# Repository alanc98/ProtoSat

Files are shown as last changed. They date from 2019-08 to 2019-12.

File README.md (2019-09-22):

# ProtoSat
Proto-Sat Software, Designs,  and Documentation

# What is it?
Proto-Sat is a compact prototyping platform for a number of purposes including:
* Flight Software Prototyping and testing
* Robotics
* Any general Portable Raspberry Pi Projects

The Proto-Sat Zero consists of:
* A custom PCB
* A Raspberry Pi Zero W
* An Adafruit PowerBoost 1000C Battery/Charge controller breakout
* A BerryIMU 10 DOF IMU with a number of sensors
* An Adafruit APDS9660 Light/Proximity Sensor
* An Adafruit 1.3" OLED display for a simple UI

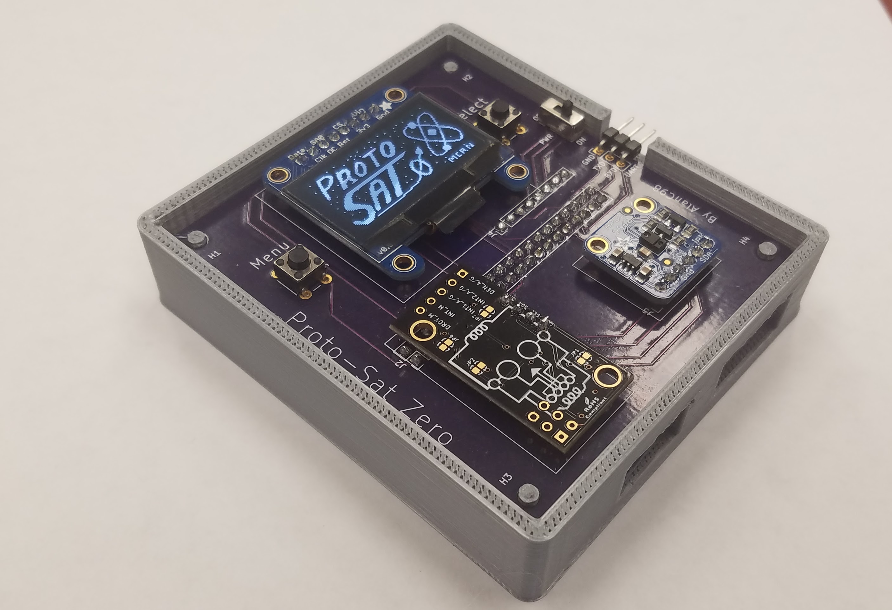
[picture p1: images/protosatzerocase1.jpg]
ProtoSatZero with 3d printed case


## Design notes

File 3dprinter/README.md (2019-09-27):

# ProtoSat 3d Printer designs
Proto-Sat 3d Printer STL files.

## ProtoSat 3d printed case:
ProtoSatZero with 3d printed case

## ProtoSat 3d printed badge holder:
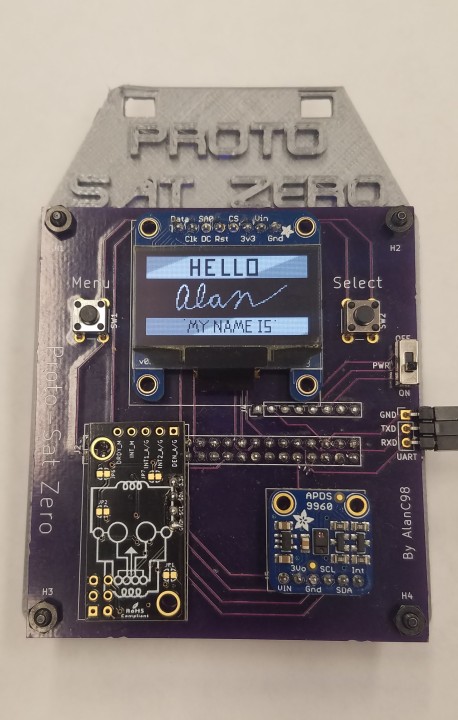
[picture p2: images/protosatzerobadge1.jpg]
ProtoSatZero with 3d printed badge holder


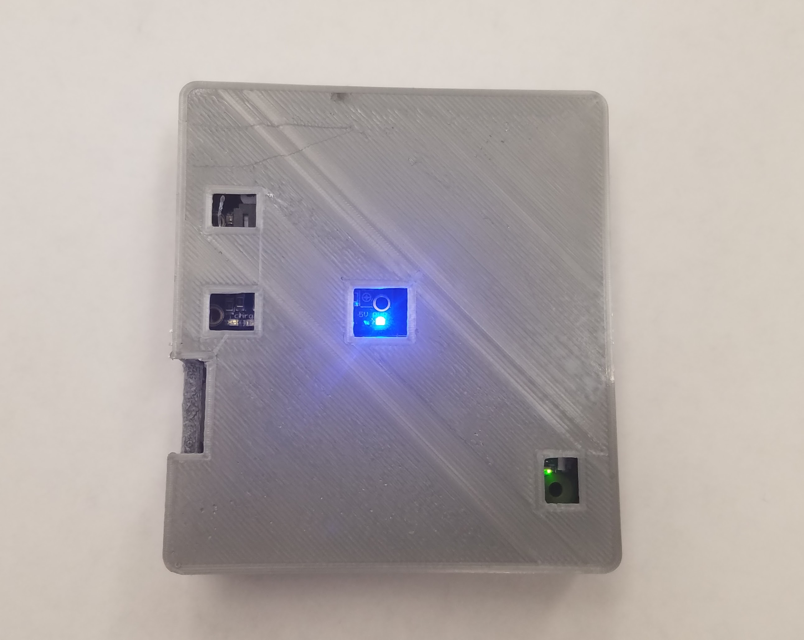
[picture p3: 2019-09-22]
images/protosatzerocase2.jpg

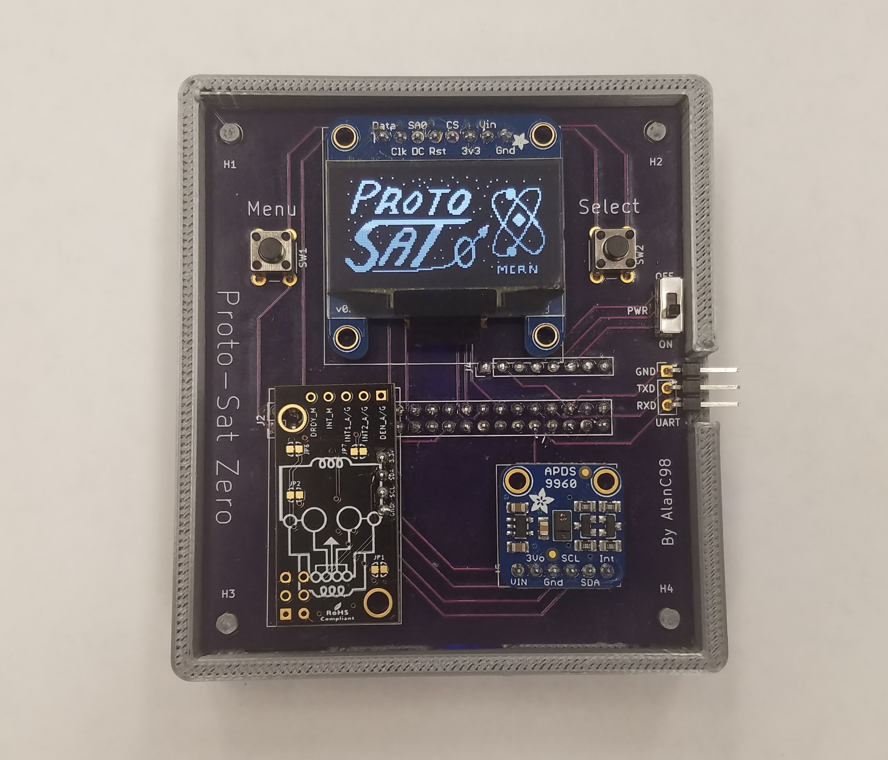
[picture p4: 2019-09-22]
images/protosatzerocase3.jpg

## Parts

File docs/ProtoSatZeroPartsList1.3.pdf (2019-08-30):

## Proto-Sat Zero Parts List

Component | Source | Cost for 1, USD
Raspberry Pi Zero W | Various (Microcenter, Adafruit, etc) | $5 to $10
Adafruit 1.3” OLED SPI Screen | https://www.adafruit.com/product/938 | $19.95
Adafruit APDS9960 Proximity, Light, Gesture sensor | https://www.adafruit.com/product/3595 | $7.50
Adafruit Powerboost 1000 Charger board | https://www.adafruit.com/product/2465 | $19.95
6mm Buttons | https://www.adafruit.com/product/367 | $0.25 (pack of 10 or $2.50)
500mAh Battery | https://www.adafruit.com/product/1578 | $7.95
BerryIMU v2 | http://ozzmaker.com/product/berryimu-accelerom eter-gyroscope-magnetometer-barometricaltitude-sensor/ (http://ozzmaker.com/product/berryimu-accelerometer-gyroscope-magnetometer-barometricaltitude-sensor/) | $25 (AUD), or approx $17 USD
Breadboard friendly switch | Several, such as: https://www.adafruit.com/product/805 or Amazon | $0.95
PCB | TBD | TBD
Headers | Standard breadboard breakaway headers from Amazon or other sources | TBD
Raspberry Pi 40 pin header | Various Sources | Approx $1.00
90 Degree 3 pin header for UART cable | Various Sources, alternate: straight header | TBD
MicroSD Card, 8+ GB | Various sources | $5 and up
3d Printed Case | TBD | TBD
Mounting Screws | TBD | TBD

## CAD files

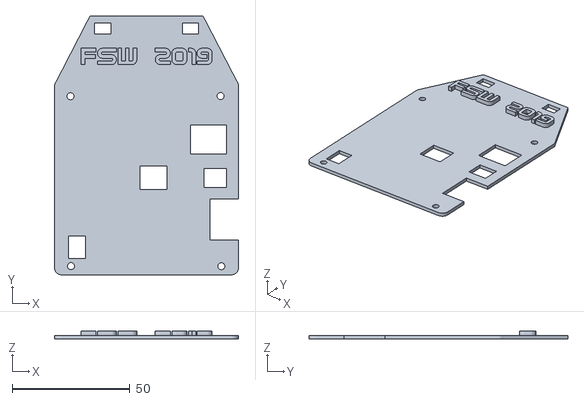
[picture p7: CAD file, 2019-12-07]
3dprinter/stl/FSW-Workshop-Badge-005.stl
78.0 x 109.7 x 3.60

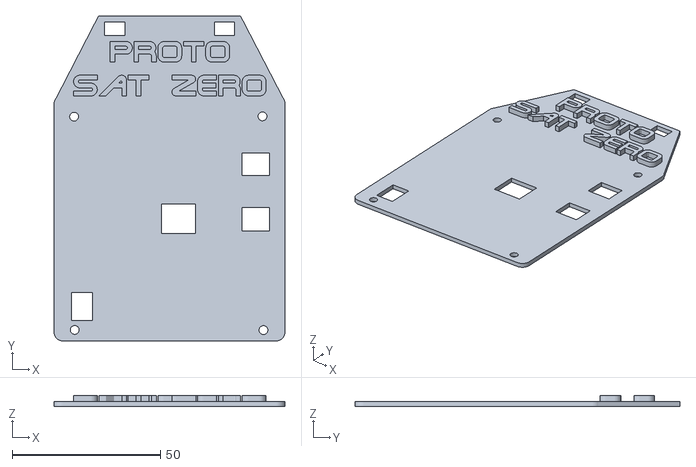
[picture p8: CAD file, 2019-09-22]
3dprinter/stl/ProtoSatZero-Badge-003.stl
78.0 x 109.7 x 3.60

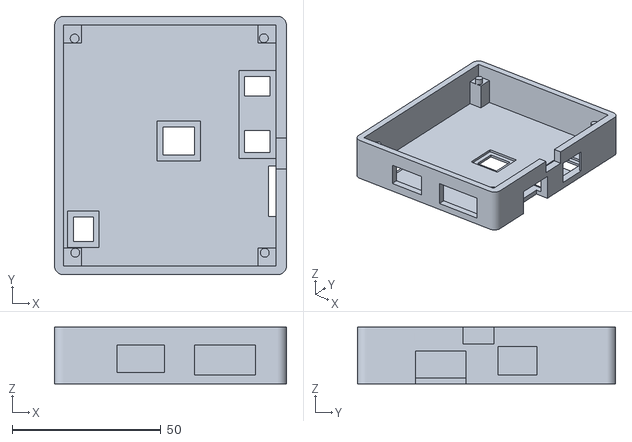
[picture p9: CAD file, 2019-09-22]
3dprinter/stl/ProtoSatZero-Case-012.stl
78.0 x 86.9 x 19.0

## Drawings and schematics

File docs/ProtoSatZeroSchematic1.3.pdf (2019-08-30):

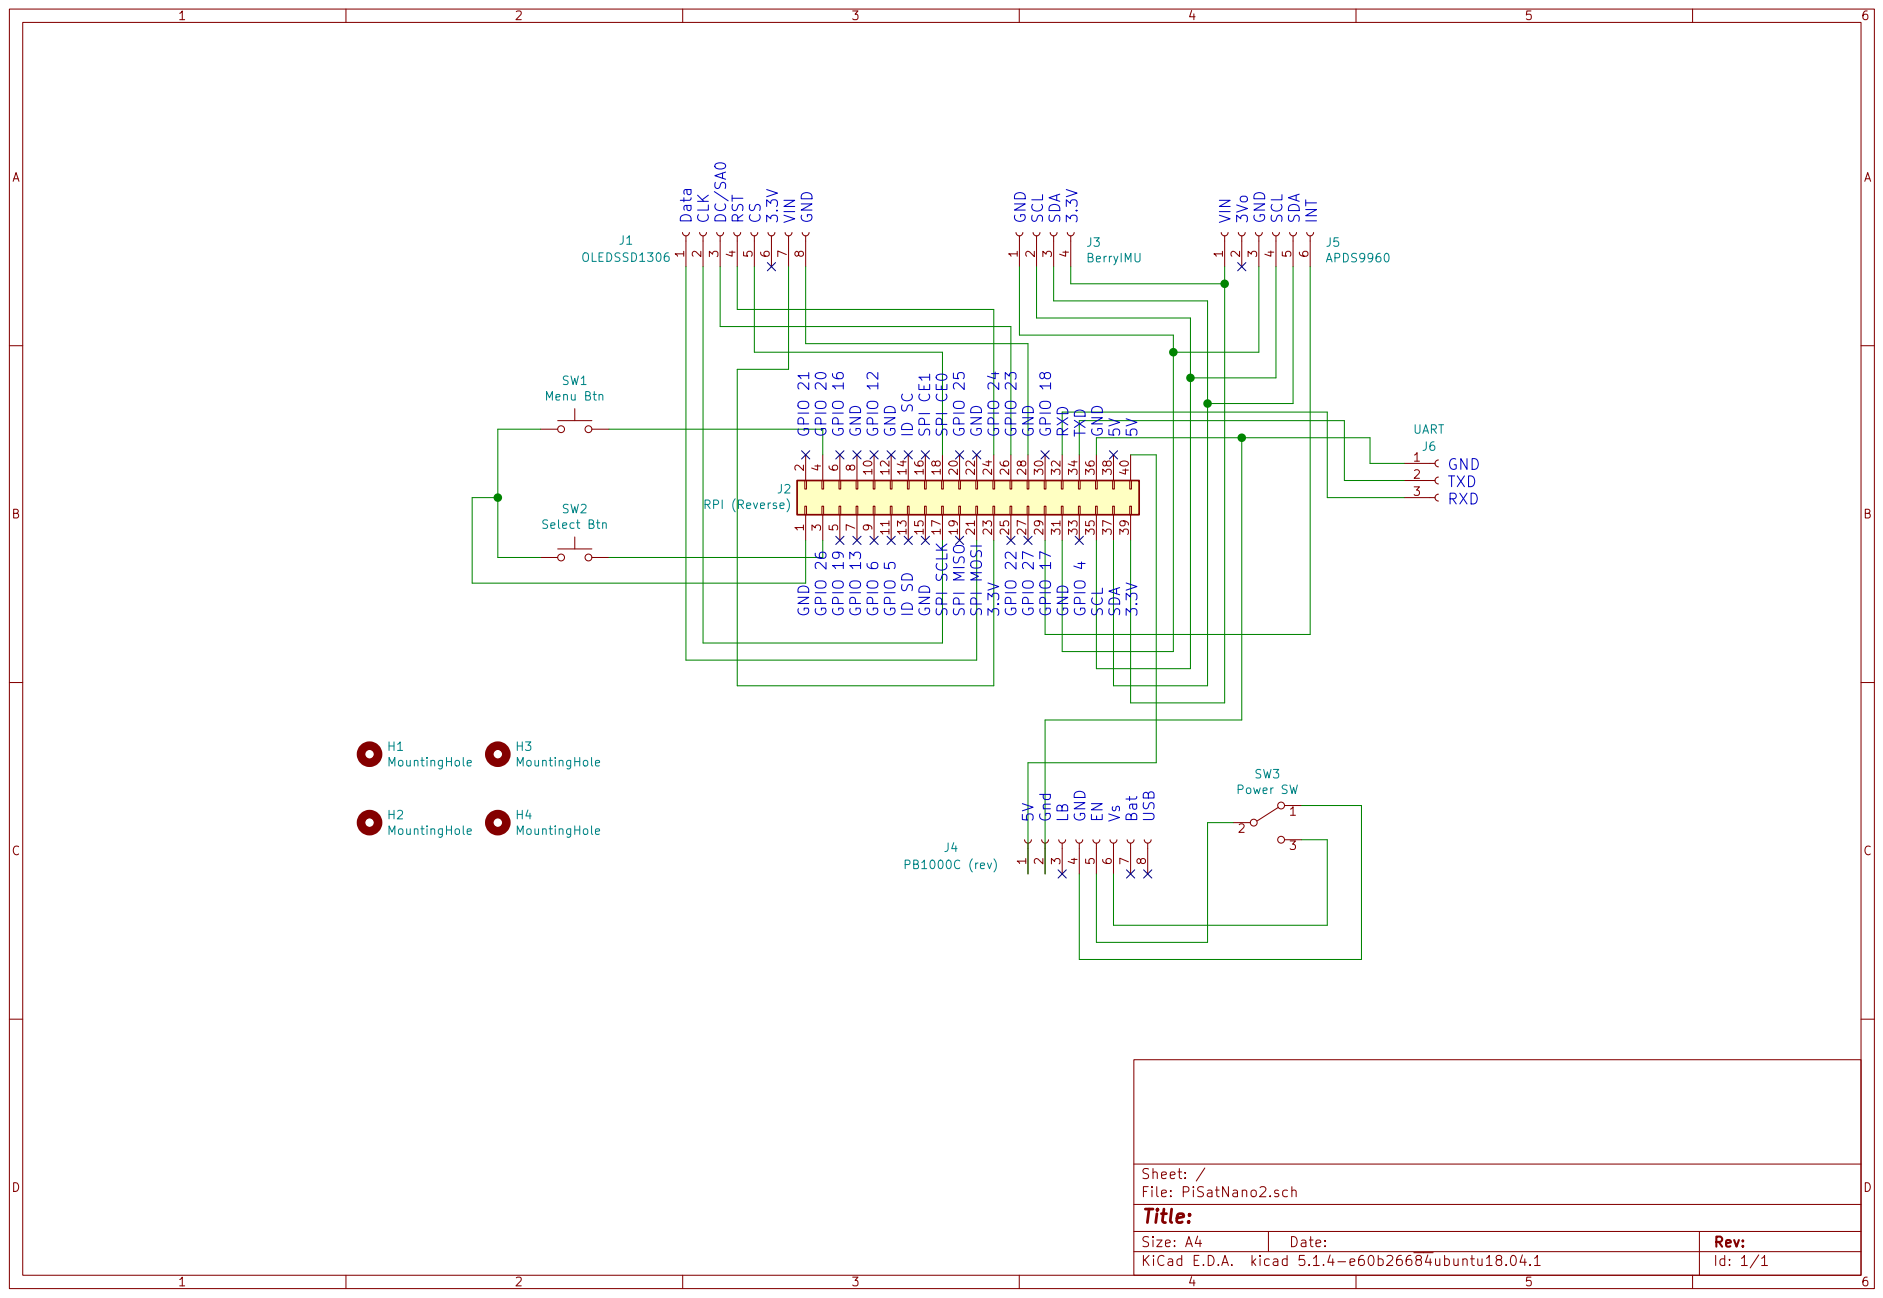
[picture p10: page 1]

J3BerryIMU GPIO 21 GPIO 20 GPIO 16 GND GPIO 12 GND ID SC SPI CE1 SPI CE0 GPIO 25 GND GPIO 24 GPIO 23 GND GPIO 18 RXD TXD GND 5V5V

Id: 1/1 Title: File: PiSatNano2.sch Sheet: /

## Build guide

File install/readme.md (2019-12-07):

* ProtoSat install / Setup

- Start with Raspian buster lite (9-26-2019)
- Write image to 16GB SD card (8 should be fine too)
```
$ sudo apt update
$ sudo apt upgrade
```

```
$ sudo raspi-config
```
Change timezone, locale, keyboard, wifi country
enable ssh
change password 
enable spi, i2c, serial console

Change password (Proto$at)

** Install dependencies:
```
$ sudo apt install git cmake python3-pip mosquitto mosquitto-clients
$ sudo pip3 install psutil
$ sudo pip3 install paho-mqtt
$ sudo pip3 install Adafruit-SSD1306
```
Note: the Adafruit-SSD1306 library that the piui GUI uses is obsolete.. need to upgrade to Circuitpython

```
sudo pip3 install adafruit-circuitpython-apds9960
sudo pip3 install adafruit-circuitpython-bmp280
sudo pip3 install adafruit-circuitpython-lsm9ds1
```

Install the protosat software

```
git clone https://github.com/alanc98/ProtoSat.git
git clone https://github.com/alanc98/cFS-mqtt-bundle.git
```

Note: The files in ~/ProtoSat/mqtt-app-config need to be copied over the default files in the cFS bundle.

- After copying, build the cFS bundle
- Copy over the ~/ProtoSat/install/rc.local file to /etc/ (need sudo)

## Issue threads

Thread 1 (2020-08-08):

Convert piui menu system to use circuitpython displayio module

alanc98, 2020-08-08:
Currently the menu system "piui" uses the retired adafruit python module for the SSD1306 display.
This menu system should be converted to use the newer Circuitpython displayio modules and the new circuitpython driver for the SSD1306 display. Currently the sensor python modules use circuitpython, so I would like all of the modules use the same hardware libraries (Circuitpython/blinka )

Another benefit of converting to blinka is that it should be easier to support newer/better/cheaper displays like the 1.3" 240x240 IPS color display that adafruit sells.

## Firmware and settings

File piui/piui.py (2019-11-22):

# 
# PiUi menu system for Adafruit SSD1306 display
#
#  For the Raspberry Pi computer. 
#  Menus are controlled by switch buttons connected to GPIO pins
#  Currently setup for 2 buttons:
#  Up = GPIO 20
#  Down = GPIO 21
#  Select = GPIO 26
#
#  (c) 2017-2019 Alan Cudmore
# 
# Uses original SSD1306 code: 
#   Copyright (c) 2014 Adafruit Industries
#   by: Tony DiCola
#
# Notes:
#  1. This will be expanded to support additional display types
#  2. I am also planning on converting the display code to use Blinka/CircuitPython libraries
#  3. I am currently using python3 to develop and run this
#
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
#
import time
import os
import sys
import socket
import subprocess
import paho.mqtt.client as mqtt
from   PIL import Image
from   PIL import ImageDraw
from   PIL import ImageFont

#
# Hardware Specific Libs
#
import Adafruit_GPIO.SPI as SPI
import RPi.GPIO as GPIO
import Adafruit_SSD1306

#
# Import the screen definitions
#
from   screens_dict import screens 

#
# Import the CVT definitions
#
from  cvt_dict import cvt

#
# MQTT broker_address
#
mqtt_broker_address = '127.0.0.1'

#
# Button - sleep delay
#
BUTTON_DELAY = 0.04

#
# Telemetry - sleep delay
# 
TELEMETRY_DELAY = 0.5

# 
# Raspberry Pi SPI pin configuration:
#
RST        = 24
DC         = 23
SPI_PORT   = 0
SPI_DEVICE = 0

#
# Globals
#
current_menu_item   = 4
current_screen      = 1 

#
# Poll for Button input
#
def GetButtonInput():
   # print("Get Button Input")
   action = "none"
   exit_loop = False
   while exit_loop == False:
      if (GPIO.input(20) == False):
         exit_loop = True
         action = "move"
      elif (GPIO.input(21) == False):
         exit_loop = True
         action = "move"
      elif (GPIO.input(26)== False):
         exit_loop = True
         action = "select"
      time.sleep(BUTTON_DELAY)  
   return action    

#
# Check button state 
#
def CheckButtonState():
   if (GPIO.input(20) == False):
      return True
   elif (GPIO.input(21) == False):
      return True
   elif (GPIO.input(26)== False):
      return True
   time.sleep(TELEMETRY_DELAY)  
   return False

#
# Initialize Display
#  This will be HW/screen specific
# 
def DisplayInitialize():
   disp = Adafruit_SSD1306.SSD1306_128_64(rst=RST, dc=DC, spi=SPI.SpiDev(SPI_PORT, SPI_DEVICE, max_speed_hz=8000000))
   return disp

#
# Clear the Display
#
def DisplayClear():
   global disp
   disp.clear()
   disp.display()

#
# Display an image
# 
def DisplayShowImage(image):
   global disp
   disp.image(image)
   disp.display()
  
#
# Load the font
#
def LoadFont():
   font = ImageFont.load_default()
   return font 

#
# Draw a Graphics screen 
#
def DisplayGraphicsScreen(graphics_screen):
   global current_menu_item

   # print("Graphics Screen display")
   # print("Display image: " + screens[graphics_screen]["imagefile"])

   #
   # Common display code ------------------------------------------------
   DisplayClear()
   image = Image.open(screens[graphics_screen]["imagefile"]).convert('1')
   DisplayShowImage(image)
   # End common Display code --------------------------------------------
   #

   action = GetButtonInput()
   exit_screen = screens[graphics_screen]["exit_to"]
   if screens[exit_screen]["screen_type"] == "menu":
      current_menu_item = screens[exit_screen]["first_menu"]
   
   return exit_screen

# 
# DisplayTextScript: This function displays a text screen and
# executes a script.
# This is used for screens like "please wait for system shutdown"
#  where the text is displayed, then the shutdown script is executed.
# The end result does not have to be a reboot or shutdown, the script
# can complete allowing the screen to timeout and return. 
#
def DisplayTextScript(text_screen):
   global current_menu_item

   #
   # Common display code -----------------------------------
   DisplayClear()

   # Create blank image for drawing.
   # Make sure to create image with mode '1' for 1-bit color.
   width = disp.width 
   height = disp.height
   image = Image.new('1', (width, height))
   # Get drawing object to draw on image.
   draw = ImageDraw.Draw(image)

   # Draw some shapes.
   # First define some constants to allow easy resizing of shapes.
   padding = 2
   top = padding
   bottom = height-padding
   # Move left to right keeping track of the current x position for drawing shapes.
   x = padding

   #
   # Load default font.
   #
   font = LoadFont()

   #
   # End common Display code --------------------------------------------
   #

   line_to_print = " "
   #
   # Render all of the rows
   #
   for menu_index in range(1,8):
      line_to_print = screens[text_screen]["rows"][menu_index]["text"]
      # print(line_to_print)

      # Common display code -----------------------------------
      #
      draw.text((x, top), line_to_print ,  font=font, fill=255)
      top += 8
      # End common Display code --------------------------------------------
      #

   #
   # Common display code -----------------------------------
   # Display image.

   DisplayShowImage(image)

   # End common Display code --------------------------------------------
   #

   script = screens[text_screen]["script"]
   subprocess.call(script, shell=True)

   exit_screen = screens[text_screen]["exit_to"]
   if screens[exit_screen]["screen_type"] == "menu":
      current_menu_item = screens[exit_screen]["first_menu"]
   
   return exit_screen

# 
# DisplayTelemetryScreen 
#
def DisplayTelemetryScreen(telemetry_screen):
   global current_menu_item

   #
   # Common display code -------------------------
   #
   DisplayClear()

   #
   # End common Display code ---------------------
   #

   ButtonPressed = False
   fake_value = 0
   while ButtonPressed == False:
 
      #
      # Common display code -------------------------
      #
      # Create blank image for drawing.
      # Make sure to create image with mode '1' for 1-bit color.
      width = disp.width 
      height = disp.height
      image = Image.new('1', (width, height))

      # Get drawing object to draw on image.
      draw = ImageDraw.Draw(image)

      # Draw some shapes.
      # First define some constants to allow easy resizing of shapes.
      padding = 2
      top = padding
      bottom = height-padding
      # Move left to right keeping track of the current x position for drawing shapes.
      x = padding

      # Load default font.
      font = LoadFont()

      #
      # End common Display code ---------------------
      #

      line_to_print = " "
      #
      # Render all of the rows
      #
      for menu_index in range(1,8):
         if  screens[telemetry_screen]["rows"][menu_index]["type"] == "text":
            line_to_print = screens[telemetry_screen]["rows"][menu_index]["text"]
            # print(line_to_print)

            #
            # Common display code -------------------------
            draw.text((x, top), line_to_print ,  font=font, fill=255)
            top += 8
            # End common Display code ---------------------
            #

         elif screens[telemetry_screen]["rows"][menu_index]["type"] == "data":
            value_to_print = cvt[screens[telemetry_screen]["rows"][menu_index]["topic"]]["value"]
            line_to_print = screens[telemetry_screen]["rows"][menu_index]["text"] + value_to_print 
            # print(line_to_print)

            #
            # Common display code -------------------------
            draw.text((x, top), line_to_print ,  font=font, fill=255)
            top += 8
            # End common Display code ---------------------
            #

      # Display image.
      #
      # Common display code -------------------------

      DisplayShowImage(image)

      # End common Display code ---------------------
      #

      ButtonPressed = CheckButtonState()

   exit_screen = screens[telemetry_screen]["exit_to"]
   if screens[exit_screen]["screen_type"] == "menu":
      current_menu_item = screens[exit_screen]["first_menu"]
   
   return exit_screen

#
# Display a menu screen 
#
def DisplayMenuScreen(menu_screen, current_item):

   #
   # Common display code -----------------------------------
   #
   DisplayClear()

   # Create blank image for drawing.
   # Make sure to create image with mode '1' for 1-bit color.
   width = disp.width 
   height = disp.height
   image = Image.new('1', (width, height))

   # Get drawing object to draw on image.
   draw = ImageDraw.Draw(image)

   # Draw some shapes.
   # First define some constants to allow easy resizing of shapes.
   padding = 2
   top = padding
   bottom = height-padding
   # Move left to right keeping track of the current x position for drawing shapes.
   x = padding

   # Load default font.
   font = LoadFont()

   #
   # End common Display code --------------------------------------------
   #

   line_to_print = " "
   #
   # Render all of the rows
   #
   for menu_index in range(1,8):
      if  screens[menu_screen]["rows"][menu_index]["type"] == "text":
         line_to_print = screens[menu_screen]["rows"][menu_index]["text"]
         # print(line_to_print)
         draw.text((x, top), line_to_print ,  font=font, fill=255)
         top += 8
      elif screens[menu_screen]["rows"][menu_index]["type"] == "data":
         value_to_print = cvt[screens[menu_screen]["rows"][menu_index]["topic"]]["value"]
         line_to_print = screens[menu_screen]["rows"][menu_index]["text"] + value_to_print 
         # print(line_to_print)
         draw.text((x, top), line_to_print ,  font=font, fill=255)
         top += 8
      else:
         if current_item == menu_index: 
            menu_text = "[*] " + screens[menu_screen]["rows"][menu_index]["text"]
         else:
            menu_text = "[ ] " + screens[menu_screen]["rows"][menu_index]["text"]
         # print(menu_text)
         draw.text((x, top), menu_text ,  font=font, fill=255)
         top += 8

   # Display image.
   DisplayShowImage(image)

#
# ProcessMenuScreenInput
#  Just needed for menus, not telemetry or graphics
#
def ProcessMenuScreenInput():
   global current_screen
   global current_menu_item
   action = GetButtonInput()
   if action == "move":
      current_menu_item = screens[current_screen]["rows"][current_menu_item]["next"]
   elif action == "select":
      if screens[current_screen]["rows"][current_menu_item]["action"] == "script":
         script = screens[current_screen]["rows"][current_menu_item]["arg"]
         # print("Menu item " + str(current_menu_item) + " Script:" + script)
         subprocess.call(script, shell=True)
         #
      elif screens[current_screen]["rows"][current_menu_item]["action"] == "screen":
         # print("Menu item " + str(current_menu_item) + " New Screen!")
         current_screen = screens[current_screen]["rows"][current_menu_item]["arg"]
         if screens[current_screen]["screen_type"] == "menu":
            current_menu_item = screens[current_screen]["first_menu"]
      else:
         print("Invalid Menu selection")

#
# MQTT Callback function. It is called when 
# an MQTT message that you are subscribing to is received
#
def on_message(client, userdata, message):

   # print ('got a message !')
   # print (message.topic) 
   # print (message.payload.decode()) 
   try:
      # Try to store value
      cvt[message.topic]["value"] = message.payload.decode() 
   except:
      print ('oops: topic is not in cvt!')
   
#
# -------------------------- Main code -----------------------------------------
#

# 
# Initialize the 128x64 display with hardware SPI
#
disp = DisplayInitialize()

#
# Initialize library.
#
disp.begin()

#
# Clear display.
#
DisplayClear()

# Create the MQTT client object
client = mqtt.Client("PIUI")

# Set the message callback function
client.on_message = on_message

# Connect to the MQTT Broker
client.connect(mqtt_broker_address)

#
# This is the MQTT Client loop. 
# It is used to check for new messages.
# once this loop starts, the main program needs
# to sleep, or do something else  
client.loop_start()

#
# Subscribe to a topics in the CVT
#
print ("Setup subscriptions!")
for key, val in cvt.items():
    print (key, val["value"])  

for key, val in cvt.items():
    print("Subscribe to topic : ", key)
    client.subscribe(key)

#
# Setup GPIO buttons
#   Dont need one of these
#
GPIO.setmode(GPIO.BCM)
GPIO.setup(20, GPIO.IN, pull_up_down=GPIO.PUD_UP)
GPIO.setup(21, GPIO.IN, pull_up_down=GPIO.PUD_UP)
GPIO.setup(26, GPIO.IN, pull_up_down=GPIO.PUD_UP)

#
# Start of main loop 
#
while True:  
   if screens[current_screen]["screen_type"] == "menu":
      DisplayMenuScreen(current_screen, current_menu_item)
      ProcessMenuScreenInput()
   elif screens[current_screen]["screen_type"] == "graphics":
      current_screen = DisplayGraphicsScreen(current_screen)
   elif screens[current_screen]["screen_type"] == "grscript":
      current_screen = DisplayGraphicsScript(current_screen)
   elif screens[current_screen]["screen_type"] == "txscript":
      current_screen = DisplayTextScript(current_screen)
   elif screens[current_screen]["screen_type"] == "telemetry":
      current_screen = DisplayTelemetryScreen(current_screen)
   else:
      print("Invalid Screen type!")
      break
   
print("Exiting!")

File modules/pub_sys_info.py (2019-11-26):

#!/usr/bin/env python3

# Publish the following info to MQTT
# "psz/sys/ipaddr"   
# "psz/sys/hostname"
# "psz/sys/cpuutil" 
# "psz/sys/memfree" 
# "psz/sys/diskfree"

#
# Publish System data to MQTT
#
import time
import os
import sys
import socket
import subprocess
import paho.mqtt.client as mqtt
import psutil

mqtt_broker_address = '127.0.0.1'
client = mqtt.Client("SYSINFO")
client.connect(mqtt_broker_address)

#
# Get the system's IP address
# Shell scripts for system monitoring from here:
#  https://unix.stackexchange.com/questions/119126/command-to-display-memory-usage-disk-usage-and-cpu-load
# 
cmd = "hostname -I | cut -d\' \' -f1"
ip_address = subprocess.check_output(cmd, shell = True )
ip_address = ip_address.rstrip()

#
# Get Hostname
#
hostname = socket.gethostname()

while True:

    #
    # Get CPU load average
    #
    load_avg = psutil.getloadavg()
    cpu_util = (load_avg[0] * 100)

    #
    # Get MB free on root disk
    #
    disk_usage = psutil.disk_usage('/')
    mb_free = (disk_usage[2] / (1024*1024))

    #
    # Get memory free
    #
    memory_info = psutil.virtual_memory()
    memory_avail = memory_info[1]
    mb_avail = (memory_avail / (1024*1024))

    client.publish('psz/sys/ipaddr',   ip_address)
    client.publish('psz/sys/hostname', hostname)
    client.publish('psz/sys/cpuutil',  cpu_util)
    client.publish('psz/sys/memfree', '{0:0.2f}'.format(mb_avail))
    client.publish('psz/sys/diskfree', '{0:0.2f}'.format(mb_free))

    # print ("IP Address = ", ip_address.decode())
    # print ("Hostname = ",hostname)
    # print ("Cpu util = ",cpu_util)
    # print ("Mem = ",mb_avail)
    # print ("disk = ",mb_free)

    time.sleep(5)

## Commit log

2019-08-30 renamed parts list and schematic
2019-09-22 Added pictures and 3d printer stl files
    [ProtoSatZero-Badge-003.stl, ProtoSatZero-Case-012.stl]
2019-09-27 updated 3d printer readme
2019-11-24 updated sensor pub scripts
2019-11-25 fixed error with screen
    [screens_dict.py]
2019-12-04 Added a couple of cFS commands to menu
2019-12-07 added FSW workshop badge
    [FSW-Workshop-Badge-005.stl]
